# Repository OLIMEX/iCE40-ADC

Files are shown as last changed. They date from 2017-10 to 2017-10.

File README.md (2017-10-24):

# iCE40-ADC
Extension module for iCE40HX1K-EVB or iCE40HX8K-EVB.

Adds fast Analog-Digital-Converter (ADC) functionality to the main board.

You can effectively use up to 4 x iCE40-ADC with a single EVB board (or up to 2 x iCE40-ADC 
when you have iCE40-IO connected to the same bus).

You can use the exported PDFs to access the schematic or the bill of materials. 

We used the latest KiCad night builds to create the design. Please use a new version KiCad to open it. 

License information should be found in LICENSE.txt

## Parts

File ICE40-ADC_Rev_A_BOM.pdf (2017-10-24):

ICE40-ADC_Rev_A | 29.03.2016
Quantity Designation | Package | Designator
2 | NA(22uF/6.3V/0603) | C_0603 | C8,C9
2 | 1uF/6.3V/0603 | C_0603 | C11,C16
4 | 22uF/6.3V/0603 | C_0603 | C1,C3,C4,C14
1 | NA(10pF) | C_0402 | C12
1 | NA | C_0402 | C13
7 | 100nF | C_0402 | C15,C2,C5,C6,C7,C10,C17
2 | 10k | R_0402 | R1,R7
3 | NA | R_0402 | R2,R3,R8
1 | 22R | R_0402 | R4
1 | NA(22R) | R_0402 | R5
3 | 110R/1% | R_0402 | R6,R9,R11
2 | 220R/1% | R_0402 | R10,R12
1 | 56R/1% | R_0402 | R13
2 | FB0805/600R/2A | L_0805 | L1,L2
1 | NA(TLV431BSN1T1G(SOT23-3)) | SOT-23 | SR1
1 | SN74ALVC244PWR(TSSOP-20) | TSSOP20_Pitch-0.65mm | U2
1 | ADC08100CIMTCX/NOPB(TSSOP-24) | TSSOP-24_Pitch-0.65mm | U1
1 | IDC34R | IDC34R_PCB | GPIO_In1
1 | BH34R | BH34R | GPIO_Out1
1 | NA(BC817-40(SOT-23)) | SOT23 | Q1
1 | BNC-JD11-50-LF | BNC-JD11-50-LF | SIG_IN1
1 | Soldered | SJ | SEL1
3 | Opened | SJ | SEL2,SEL3,SEL4

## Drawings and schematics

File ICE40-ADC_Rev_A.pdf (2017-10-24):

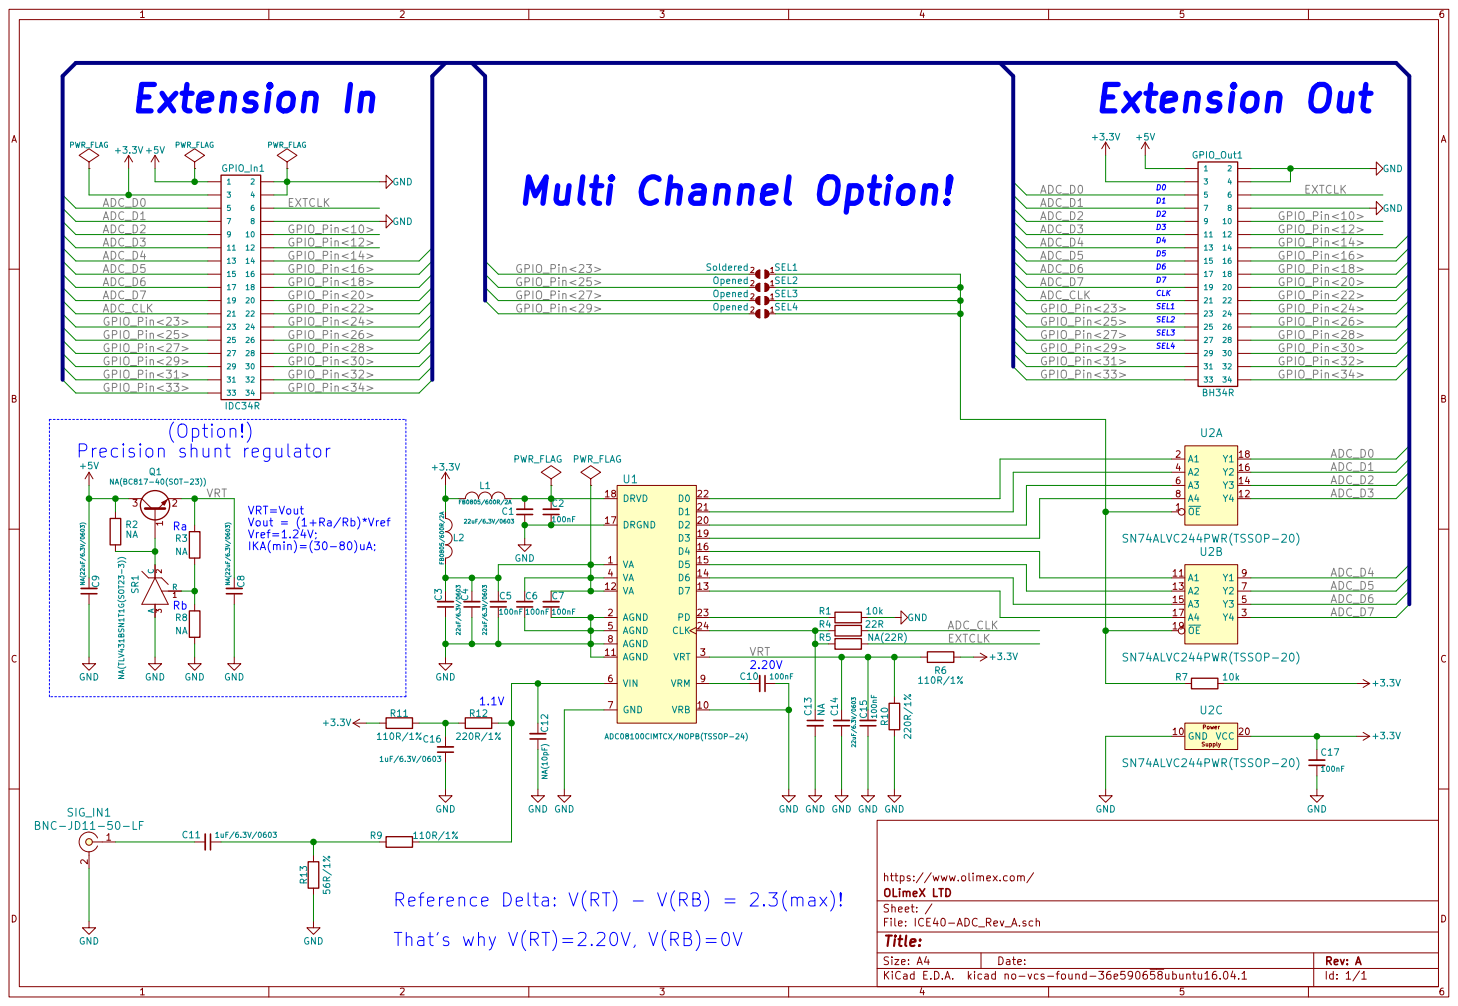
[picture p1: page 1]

1.1V Reference Delta: V(RT) - V(RB) = 2.3(max)!

File: ICE40-ADC_Rev_A.sch Sheet: / OLimeX LTD

That's why V(RT)=2.20V, V(RB)=0V

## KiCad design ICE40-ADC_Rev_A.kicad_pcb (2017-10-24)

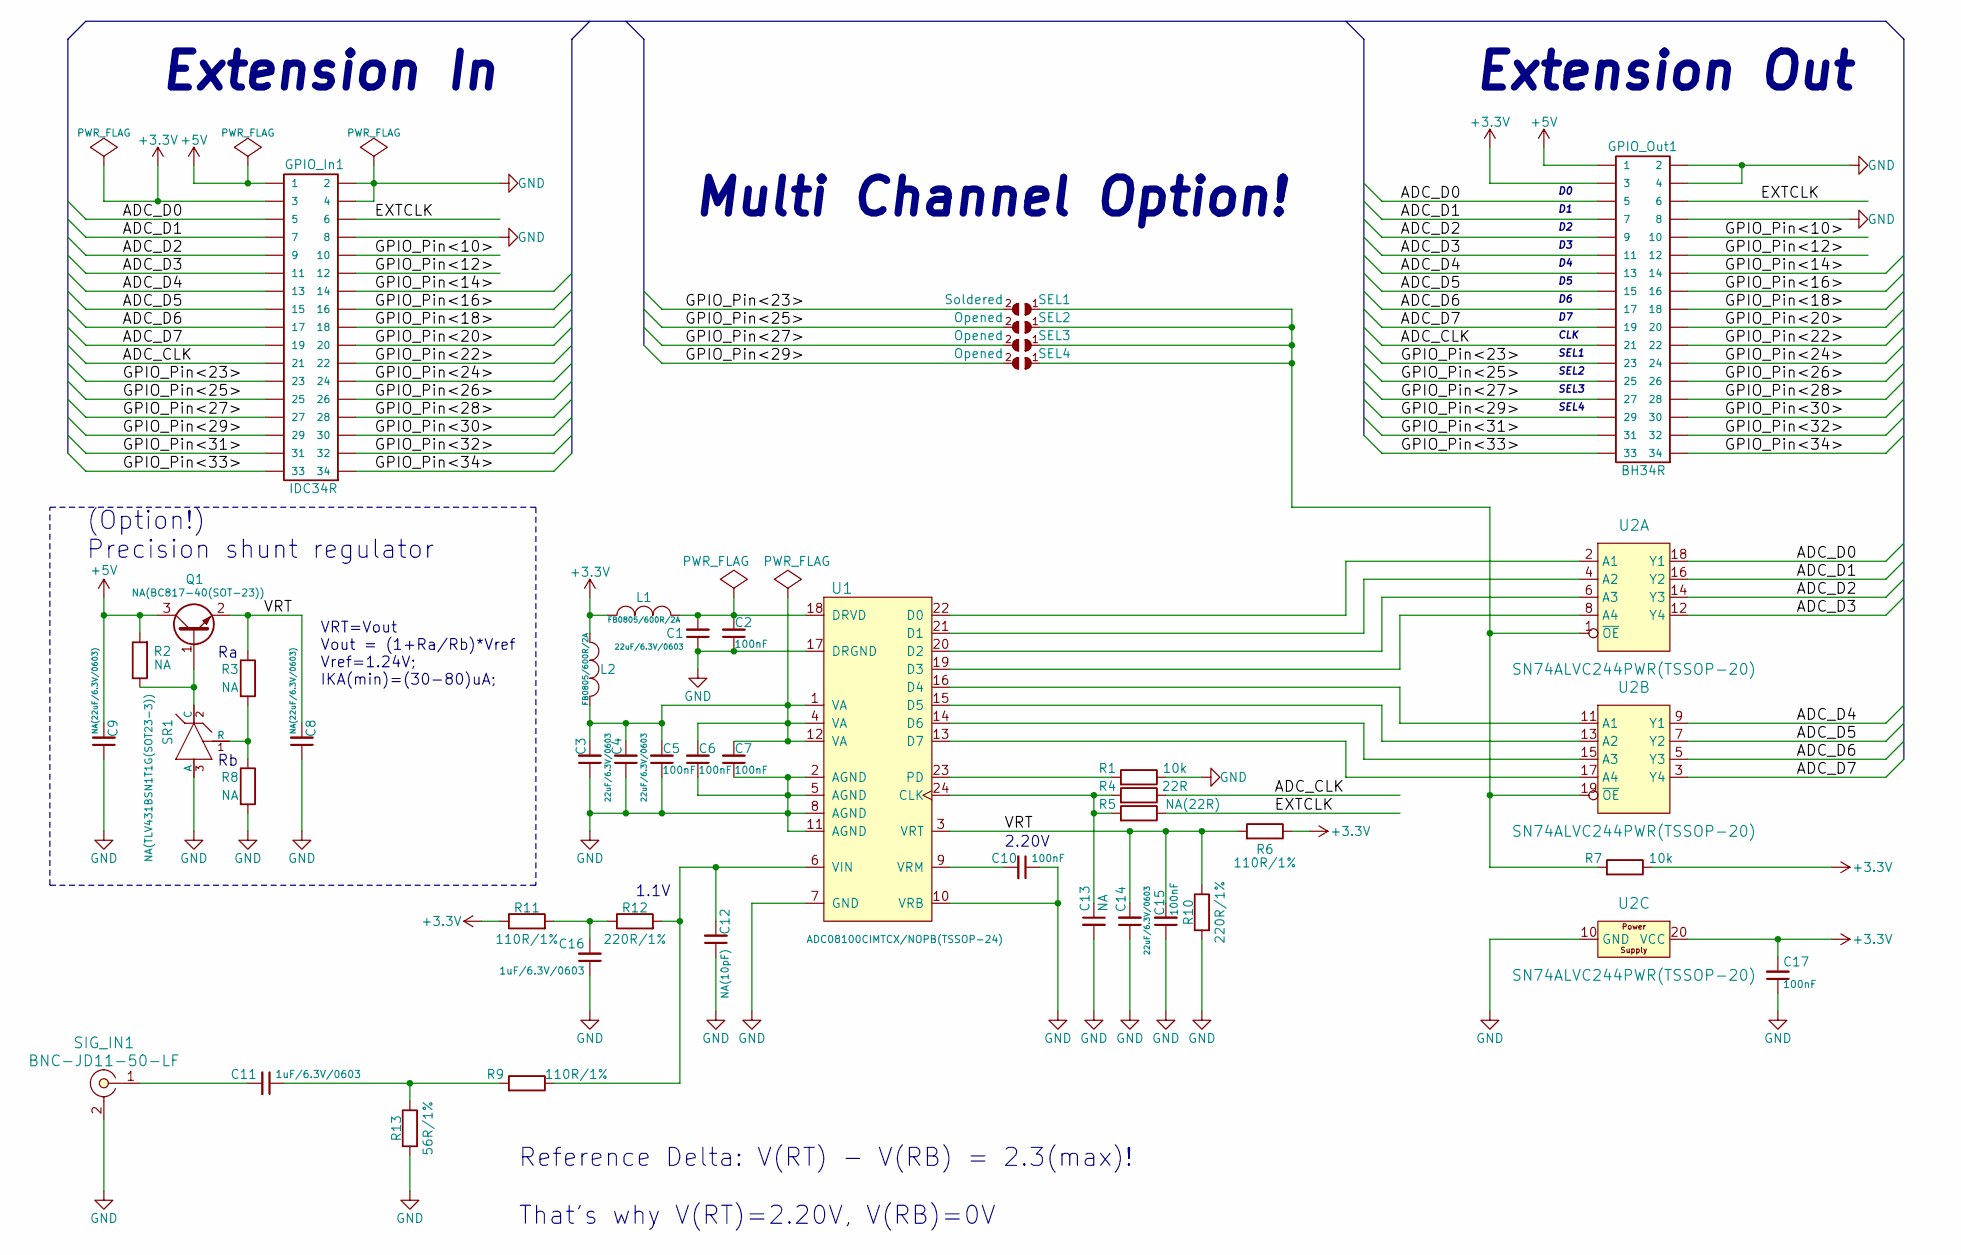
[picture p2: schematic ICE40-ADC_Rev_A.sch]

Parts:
C1, C3, C4, C14: 22uF/6.3V/0603; C_0603_5MIL_DWS
C2, C5, C6, C7, C10, C15, C17: 100nF; C_0402_5MIL_DWS
C8, C9: NA(22uF/6.3V/0603); C_0603_5MIL_DWS
C11, C16: 1uF/6.3V/0603; C_0603_5MIL_DWS
C12: NA(10pF); C_0402_5MIL_DWS
C13: NA; C_0402_5MIL_DWS
GPIO_In1: IDC34R; IDC34R_PCB
GPIO_Out1: BH34R
L1, L2: FB0805/600R/2A; L_0805_5MIL_DWS
Q1: NA(BC817-40(SOT-23)); SOT23
R1, R7: 10k; R_0402_5MIL_DWS
R2, R3, R8: NA; R_0402_5MIL_DWS
R4: 22R; R_0402_5MIL_DWS
R5: NA(22R); R_0402_5MIL_DWS
R6, R9, R11: 110R/1%; R_0402_5MIL_DWS
R10, R12: 220R/1%; R_0402_5MIL_DWS
R13: 56R/1%; R_0402_5MIL_DWS
SEL1: Soldered; SJ
SEL2, SEL3, SEL4: Opened; SJ
SIG_IN1: BNC-JD11-50-LF; BNC-JD11-50-LF_1-IN_2-GND
SR1: NA(TLV431BSN1T1G(SOT23-3)); SOT-23
U1: ADC08100CIMTCX/NOPB(TSSOP-24); TSSOP-24_Pitch-0.65mm_7.80x6.40x1.20mm
U2: SN74ALVC244PWR(TSSOP-20); TSSOP20_Pitch-0.65mm_6.6x4.5x1.2mm

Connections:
+3V3: C17.2, GPIO_In1.3, GPIO_Out1.3, L1.2, L2.2, R6.1, R7.1, R11.1, U2.20 (VCC)
+5V: C9.2, GPIO_In1.1, GPIO_Out1.1, Q1.3 (C), R2.2
/ADC_CLK: GPIO_In1.21, GPIO_Out1.21, R4.1
/ADC_D0: GPIO_In1.5, GPIO_Out1.5, U2.18 (Y1)
/ADC_D1: GPIO_In1.7, GPIO_Out1.7, U2.16 (Y2)
/ADC_D2: GPIO_In1.9, GPIO_Out1.9, U2.14 (Y3)
/ADC_D3: GPIO_In1.11, GPIO_Out1.11, U2.12 (Y4)
/ADC_D4: GPIO_In1.13, GPIO_Out1.13, U2.9 (Y1)
/ADC_D5: GPIO_In1.15, GPIO_Out1.15, U2.7 (Y2)
/ADC_D6: GPIO_In1.17, GPIO_Out1.17, U2.5 (Y3)
/ADC_D7: GPIO_In1.19, GPIO_Out1.19, U2.3 (Y4)
/EXTCLK: GPIO_In1.6, GPIO_Out1.6, R5.1
/GPIO_Pin<10>: GPIO_In1.10, GPIO_Out1.10
/GPIO_Pin<12>: GPIO_In1.12, GPIO_Out1.12
/GPIO_Pin<14>: GPIO_In1.14, GPIO_Out1.14
/GPIO_Pin<16>: GPIO_In1.16, GPIO_Out1.16
/GPIO_Pin<18>: GPIO_In1.18, GPIO_Out1.18
/GPIO_Pin<20>: GPIO_In1.20, GPIO_Out1.20
/GPIO_Pin<22>: GPIO_In1.22, GPIO_Out1.22
/GPIO_Pin<23>: GPIO_In1.23, GPIO_Out1.23, SEL1.2
/GPIO_Pin<24>: GPIO_In1.24, GPIO_Out1.24
/GPIO_Pin<25>: GPIO_In1.25, GPIO_Out1.25, SEL2.2
/GPIO_Pin<26>: GPIO_In1.26, GPIO_Out1.26
/GPIO_Pin<27>: GPIO_In1.27, GPIO_Out1.27, SEL3.2
/GPIO_Pin<28>: GPIO_In1.28, GPIO_Out1.28
/GPIO_Pin<29>: GPIO_In1.29, GPIO_Out1.29, SEL4.2
/GPIO_Pin<30>: GPIO_In1.30, GPIO_Out1.30
/GPIO_Pin<31>: GPIO_In1.31, GPIO_Out1.31
/GPIO_Pin<32>: GPIO_In1.32, GPIO_Out1.32
/GPIO_Pin<33>: GPIO_In1.33, GPIO_Out1.33
/GPIO_Pin<34>: GPIO_In1.34, GPIO_Out1.34
/VRT: C8.2, C14.2, C15.2, Q1.2 (E), R3.1, R6.2, R10.1, U1.3 (VRT)
GND: C1.1, C2.1, C3.1, C4.1, C5.1, C6.1, C7.1, C8.1, C9.1, C10.1, C12.1, C13.2, C14.1, C15.1, C16.1, C17.1, GPIO_In1.2, GPIO_In1.4, GPIO_In1.8, GPIO_Out1.2, GPIO_Out1.4, GPIO_Out1.8, R1.1, R8.2, R10.2, R13.2, SIG_IN1.2, SR1.3 (A), U1.2 (AGND), U1.5 (AGND), U1.7 (GND), U1.8 (AGND), U1.10 (VRB), U1.11 (AGND), U1.17 (DRGND), U2.10 (GND)
unnamed: C1.2, C2.2, L1.1, U1.18 (DRVD)
unnamed: C3.2, C4.2, C5.2, C6.2, C7.2, L2.1, U1.1 (VA), U1.4 (VA), U1.12 (VA)
unnamed: C10.2, U1.9 (VRM)
unnamed: C11.1, R9.2, R13.1
unnamed: C11.2, SIG_IN1.1
unnamed: C12.2, R9.1, R12.2, U1.6 (VIN)
unnamed: C13.1, R4.2, R5.2, U1.24 (CLK)
unnamed: C16.2, R11.2, R12.1
unnamed: Q1.1 (B), R2.1, SR1.2 (C)
unnamed: R1.2, U1.23 (PD)
unnamed: R3.2, R8.1, SR1.1 (R)
unnamed: R7.2, SEL1.1, SEL2.1, SEL3.1, SEL4.1, U2.1 (~OE), U2.19 (~OE)
unnamed: U1.13 (D7), U2.17 (A4)
unnamed: U1.14 (D6), U2.15 (A3)
unnamed: U1.15 (D5), U2.13 (A2)
unnamed: U1.16 (D4), U2.11 (A1)
unnamed: U1.19 (D3), U2.8 (A4)
unnamed: U1.20 (D2), U2.6 (A3)
unnamed: U1.21 (D1), U2.4 (A2)
unnamed: U1.22 (D0), U2.2 (A1)

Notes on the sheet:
Extension Out
Extension In
VRT=Vout Vout = (1+Ra/Rb)*Vref Vref=1.24V; IKA(min)=(30-80)uA;
2.20V
1.1V
Reference Delta: V(RT) - V(RB) = 2.3(max)! That's why V(RT)=2.20V, V(RB)=0V
(Option!) Precision shunt regulator
Multi Channel Option!
CLK
SEL1
SEL2
SEL3
SEL4

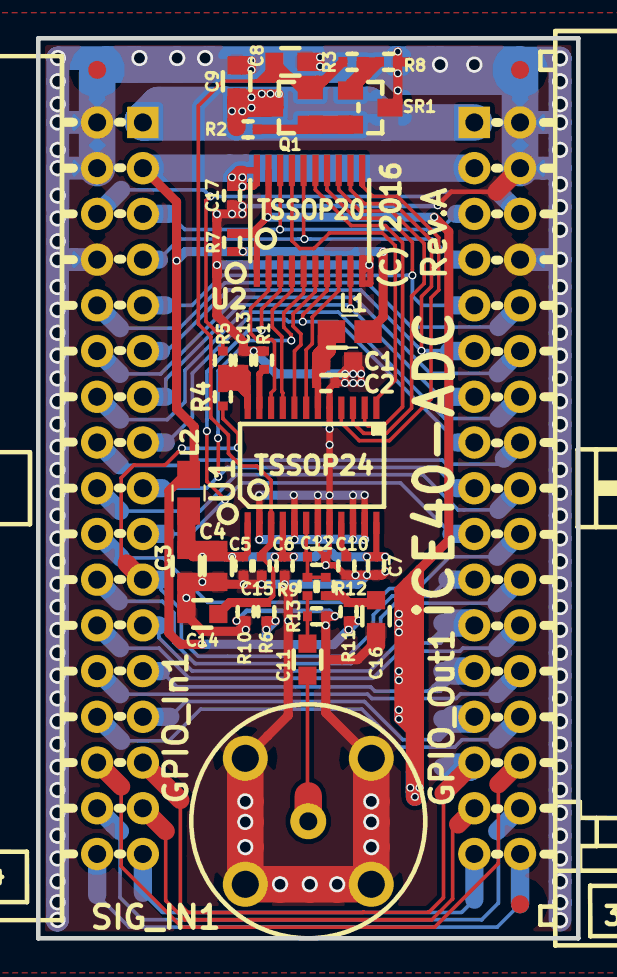
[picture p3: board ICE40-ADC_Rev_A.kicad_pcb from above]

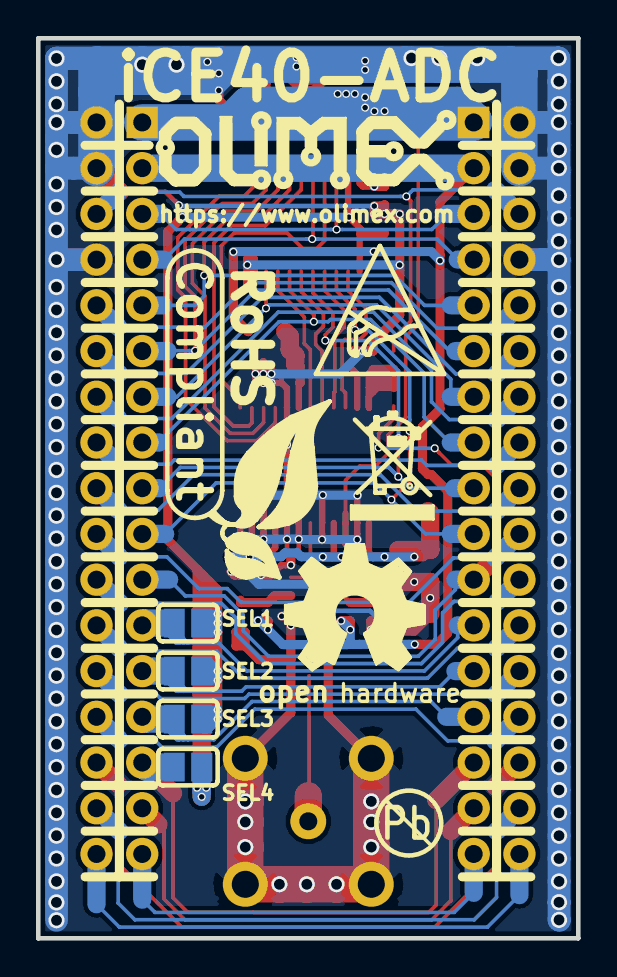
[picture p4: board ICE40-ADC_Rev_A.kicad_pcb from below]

Board: 2 copper layers, 30.0 x 50.0 mm, 45 parts (6 on the bottom side), 53 nets.

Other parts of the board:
Ref**: Val**; LOGO_ANTISTATIC_1
Ref**#2: Val**; LOGO_ROHS_1

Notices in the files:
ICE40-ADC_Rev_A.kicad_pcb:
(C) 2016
